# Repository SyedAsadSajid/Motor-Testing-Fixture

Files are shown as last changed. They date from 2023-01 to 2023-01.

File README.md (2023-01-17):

# Motor-Testing-Fixture
This is project is a Motor Driver Shield for the L298N that I designed to use as a motor testing fixture. It can run up to 6 motors at once.
The nature of the testing was lifecycle testing so the PCB has a built-in counter feature that counts the number of cycles the motors have 
been running for. The entire fixture consists of the PCB design that is included, a counter, and then an Arduino to run the Motor test fixture code. 
The code also contains current sensing so once a motor has died, the fixture will stop until the motor has been removed or replaced and the fixture 
is restarted.

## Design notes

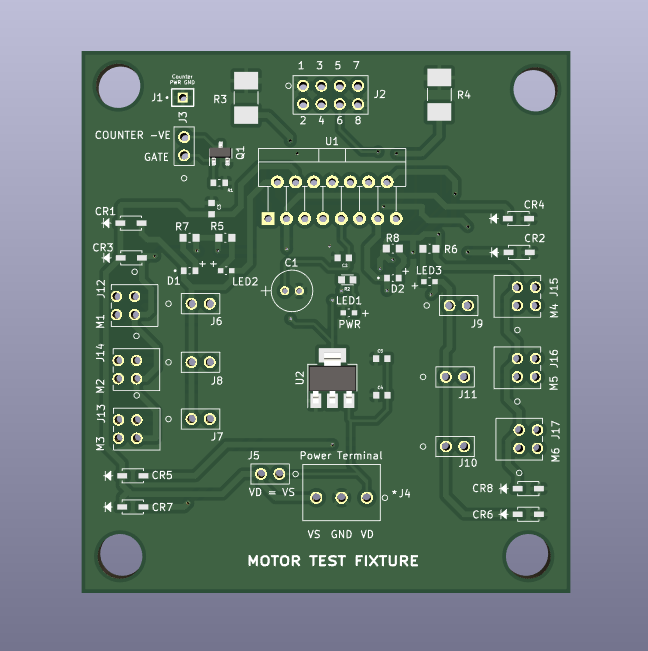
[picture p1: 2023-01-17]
3D_View_L298N_Motor_Driver_Shield.png

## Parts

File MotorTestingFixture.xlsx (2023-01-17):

Source: | C:\Users\AsadSajid\OneDrive - Limestone Labs Limited\Documents\MotorTestingFixture\MotorTestingFixture.kicad_sch
Date: | 2022-12-12 00:37
Tool: | Eeschema (6.0.9)
Generator: | C:\Program Files\KiCad\6.0\bin\scripting\plugins/bom_csv_grouped_by_value_with_fp.py
Component Count: | 45
Ref | Qnty | Value | Cmp name | Footprint | Description | DigiKey P/N
C1, | 1 | 47uF/35V | 35ZLJ47MTA5X11 | Polarized_CAP:35ZLJ47MTA5X11 |  | 1189-1630-1-ND
C2, C3, C4, C5, | 4 | 104p | CL10B103KB8NNNC | Samsung_104p_Cap:CAPC1608X90N |  | 1276-1009-2-ND - Tape & Reel (TR)
CR1, CR2, CR3, CR4, CR5, CR6, CR7, CR8 | 8 | Flyback Diodes | PMEG3020EH | FlyBack Diode:PMEG3020EH |  | 1727-3873-2-ND - Tape & Reel (TR)
D1, D2, | 2 | GREEN LED | LTST-C190KGKT | GREEN_LEDS:LEDC1608X35N |  | 160-1435-2-ND - Tape & Reel (TR)
J2, | 1 | L298N pins | 61300821121 | 8_pin_header:61300821121 |  | 732-5296-ND
J3, J5, J6, J7, J8, J9, J10, J11, | 8 | Counter Pins, VD = VS, Pin Headers | 61300211121 | 2_pin_header:61300211121 |  | 732-5315-ND
J4, | 1 | Power Terminal | 1984620 | 3_pos_terminal_block:1984620 |  | 277-1722-ND
J12, J13, J14, J15, J16, J17, | 6 | M1, M2, M3, M4, M5, M6 | 1725656 | 2_pos_terminal_block:1725656 |  | 277-1273-ND
LED1, LED2, LED3, | 3 | PWR LED, RED LED | LTST-C191KRKT | RED LEDS:LTST-C191KRKT |  | 160-1447-2-ND - Tape & Reel (TR)
Q1, | 1 | DMN10H220L | DMN10H220L | Package_TO_SOT_SMD:SOT-23 | 1.4A Id, 100V Vds, N-Channel MOSFET, SOT-23 | DMN10H220L-13DITR-ND - Tape & Reel (TR)
R1, | 1 | 500 | RT0603BRC07500RL | 500Ohm_SMD_Res:RESC1608X55N |  | 13-RT0603BRC07500RLTR-ND - Tape & Reel (TR)
R2, | 1 | 1k | 1-1614351-9 | 1kOhm_SMD_Res:RESC1608X50N |  | A105863-ND
R3, R4, | 2 | 0.5 | CRM2512-FX-R500ELF | 0.5ohm_SnapEDA:RESC6331X80N | Current Sensing Resistors, 2W | 118-CRM2512-FX-R500ELFTR-ND - Tape & Reel (TR)
R5, R6, R7, R8, | 4 | 10k | RN73C1J10KBTG | 10kOhm_SMD_Res:RN73C1J10KBTG |  | A105758-ND
U1, | 1 | L298N | L298N | Package_TO_SOT_THT:TO-220-15_P2.54x2.54mm_StaggerOdd_Lead4.58mm_Vertical | Dual full bridge motor driver, up to 46V, 4A, Multiwatt15-V | 497-1395-5-ND
U2, | 1 | LM317_SOT-223 | LM317_SOT-223 | Package_TO_SOT_SMD:SOT-223-3_TabPin2 | 1.5A 35V Adjustable Linear Regulator, SOT-223 | 296-12602-2-ND - Tape & Reel (TR)
J5, J6, J7, J8, J9, J10, J11 | 7 | VD = VS, Pin Jumpers for pin headers | QPC02SXGN-RC | ------------ | 2 Header pin jumpers | S9337-ND
J1 | 1 | Counter PWR GND | SSW-101-02-T-S | single_female_connector:SAMTEC_SSW-101-02-T-S | Counter PWR GND | SAM1222-01-ND

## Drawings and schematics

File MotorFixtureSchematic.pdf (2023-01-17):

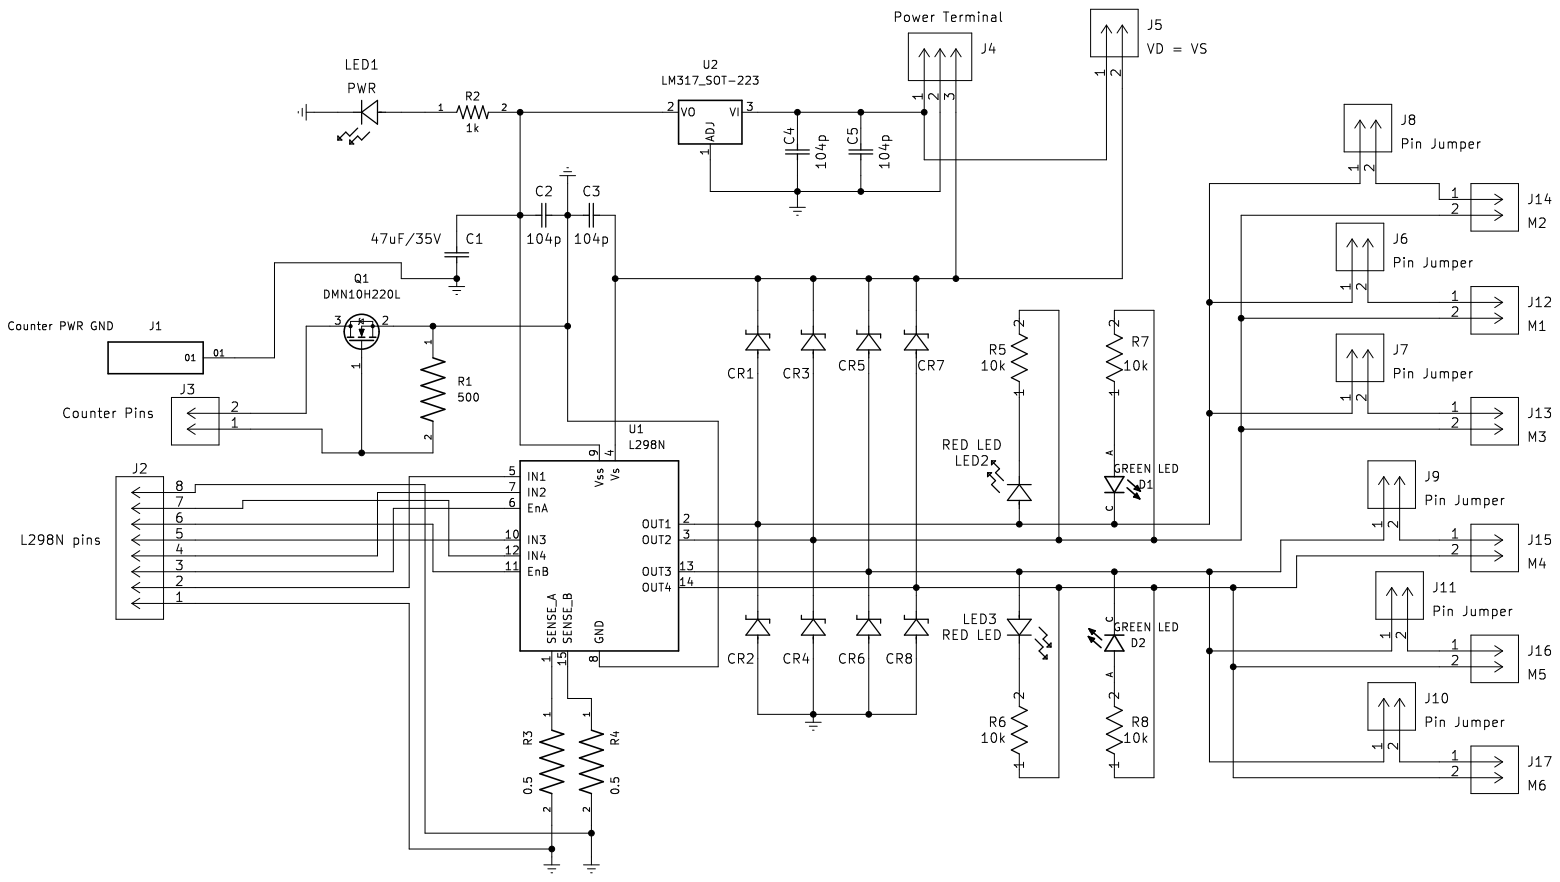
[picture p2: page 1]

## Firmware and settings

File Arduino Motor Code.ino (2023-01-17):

// connect motor controller pins to Arduino digital pins

// motor one connections
int E1 = 10;                  // J2 PIN 3
int in1 = 11;                 // J2 PIN 2
int in2 = 12;                 // J2 PIN 4
int csA = A0;                 // J2 PIN 1     

// motor two connections 
int E2 = 2;                   // J2 PIN 6
int in3 = 3;                  // J2 PIN 5
int in4 = 4;                  // J2 PIN 7
int csB = A1;                 // J2 PIN 8

// counter pin 
int counter = 5;              // J3 COUNTER -VE

// ratio between current and voltage
double currentFactor = 2/1;   // output of 1V per 2A

void setup() {
  // set all the motor control pins to outputs
  pinMode(E1, OUTPUT);
  pinMode(in1, OUTPUT);
  pinMode(in2, OUTPUT);
  pinMode(E2, OUTPUT);
  pinMode(in3, OUTPUT);
  pinMode(in4, OUTPUT);
  pinMode(counter, OUTPUT);
}

void MotorsForward() {
  // Arduino sends a low signal to counter at the beginning of the cycle
  digitalWrite(counter, LOW);
  
  // set speeds and directions of motor terminal A and motor terminal B for three seconds`
  digitalWrite(in1, HIGH);
  digitalWrite(in2, LOW);
  analogWrite(E1, 255);
  digitalWrite(in3, HIGH);
  digitalWrite(in4, LOW);
  analogWrite(E2, 255);
}  
void Brake() {
  digitalWrite(in1, LOW);
  digitalWrite(in2, LOW);
  analogWrite(E1, 0);  
  digitalWrite(in3, LOW);
  digitalWrite(in4, LOW);
  analogWrite(E2, 0);
  delay(1000);
}

void MotorsBackward() {
  digitalWrite(in1, LOW);
  digitalWrite(in2, HIGH);
  analogWrite(E1, 255);  
  digitalWrite(in3, LOW);
  digitalWrite(in4, HIGH);
  analogWrite(E2, 255); 
}

void FinishCycle(){
  Brake();
  delay(500);
  digitalWrite(counter, HIGH);
}

void loop() {
  // put your main code here, to run repeatedly:
  MotorsForward();
  double currentVB = map(analogRead(csB), 0, 1024, 0, 5000)/1000;
  double currentB = currentVB*currentFactor;
  double currentVA = map(analogRead(csA), 0, 1024, 0, 5000)/1000;
  double currentA = currentVA*currentFactor;
  if (currentA > 1.5 || currentB > 1.5){
    exit(1);
  }
  delay(3000);

  Brake();
  
  MotorsBackward();
  double RevcurrentVB = map(analogRead(csB), 0, 1024, 0, 5000)/1000;
  double RevcurrentB = RevcurrentVB*currentFactor;
  double RevcurrentVA = map(analogRead(csA), 0, 1024, 0, 5000)/1000;
  double RevcurrentA = RevcurrentVA*currentFactor;
  if (RevcurrentA > 1.5 || RevcurrentB > 1.5){
    exit(1);
  }  
  delay(3000);  

  FinishCycle();
  delay(500);

}
